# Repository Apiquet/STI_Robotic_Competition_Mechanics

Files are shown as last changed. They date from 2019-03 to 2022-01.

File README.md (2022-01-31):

EPFL Robotics Competition: mechanical design repository. 

Complete description of the job done here: https://apiquet.com/2019/08/20/epfl-robotics-competition/

# Description

The goal of the EPFL (Ecole Polytechnique Fédérale de Lausanne) Robotics Competition is to build an autonomous recycling robot.  This robot, built from scratch, must recognizes any bottle (thanks to a camera), catch it, then bring it to a recycling area.

Azzano Guilhem, Erbacher Pierre and I formed the Green Eye team, Winner of the 2019 Edition.

My responsibilities were:

- modeling the collector mecanism to catch the bottles and the system to store them: https://apiquet.com/2019/08/20/epfl-robotics-competition/

- visual recognition using Python and/or C++ to recognize the bottles and guide the robot to them: https://apiquet.com/2019/06/02/visual-recognition/

- Triangularization of the Robot’s position and orientation from an homemade Beacon: https://apiquet.com/2019/06/13/beacon/

# Our robot

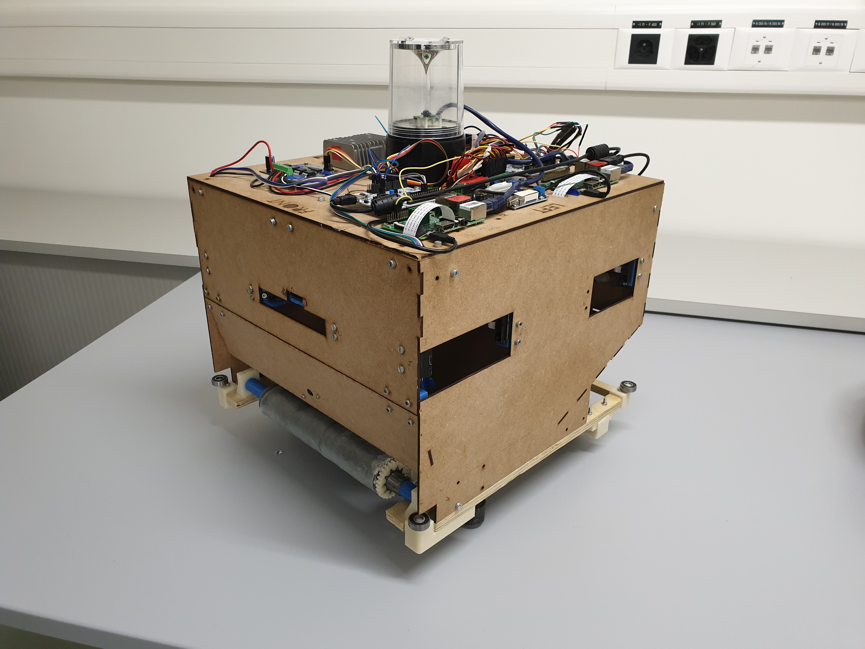
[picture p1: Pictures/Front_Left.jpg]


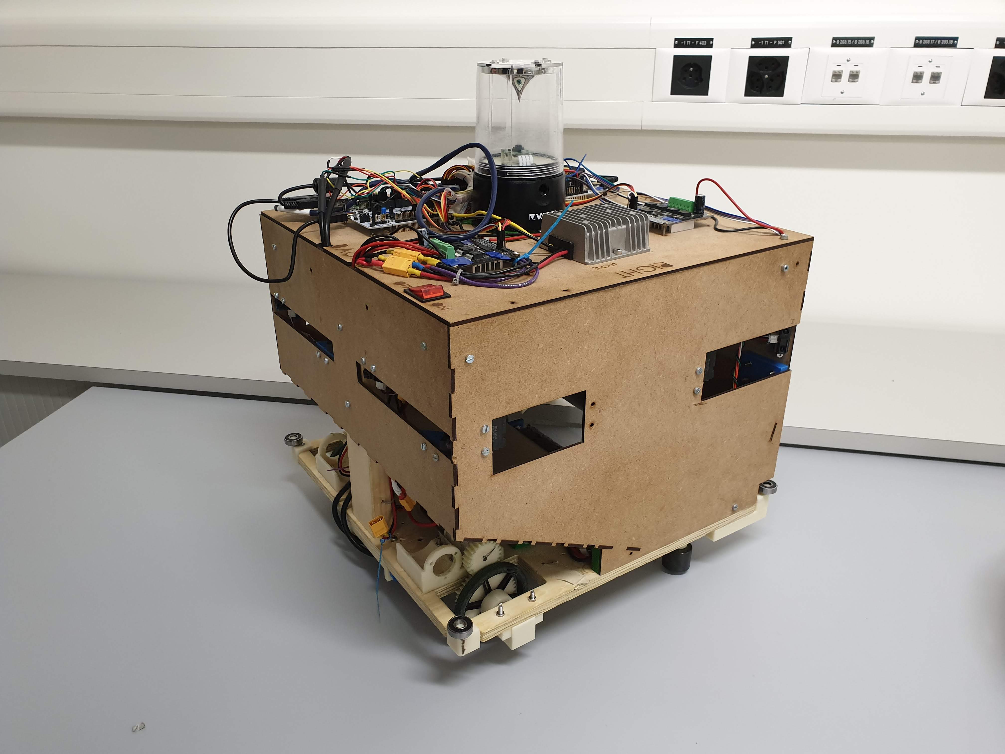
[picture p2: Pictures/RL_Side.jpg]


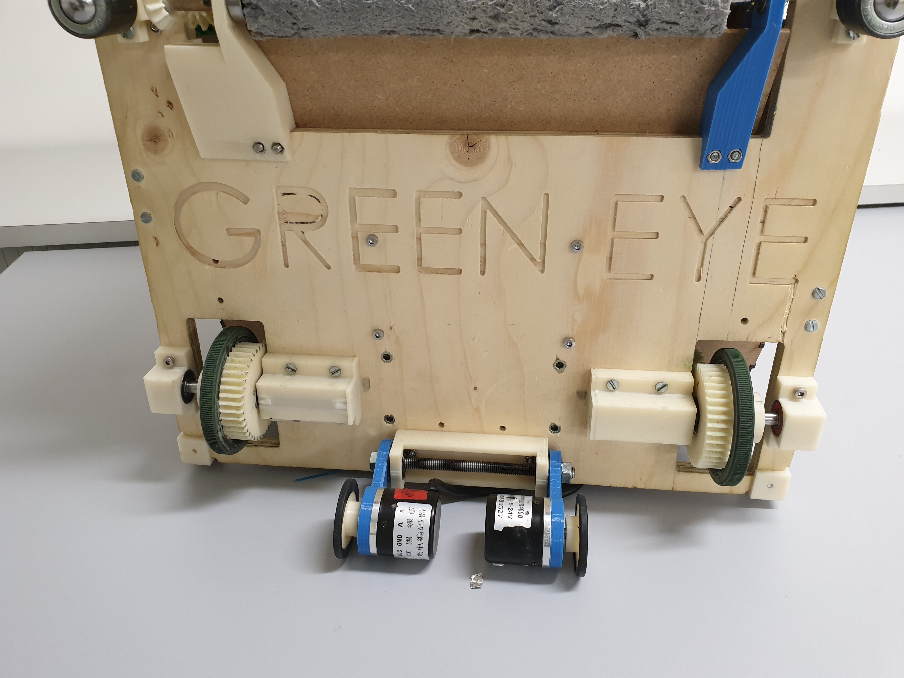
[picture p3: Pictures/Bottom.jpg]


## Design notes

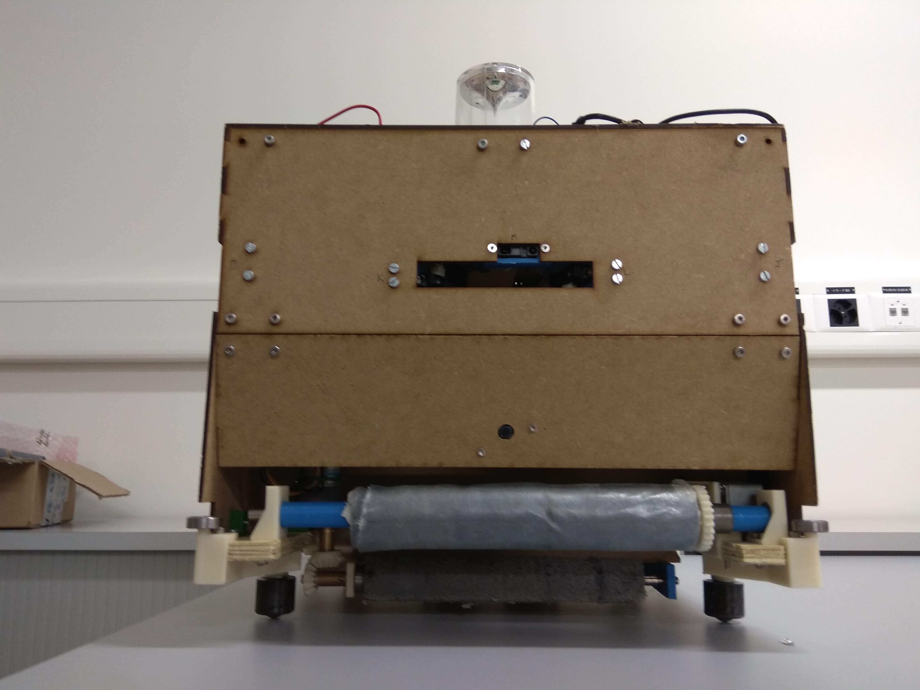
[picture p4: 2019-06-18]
Pictures/RL_Front.jpg

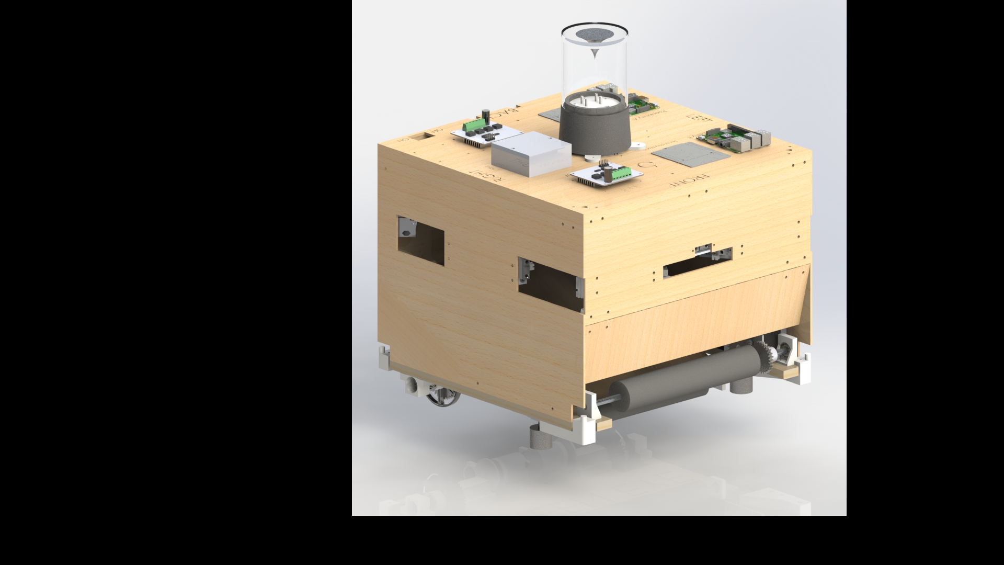
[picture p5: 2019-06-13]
Render_1.JPG

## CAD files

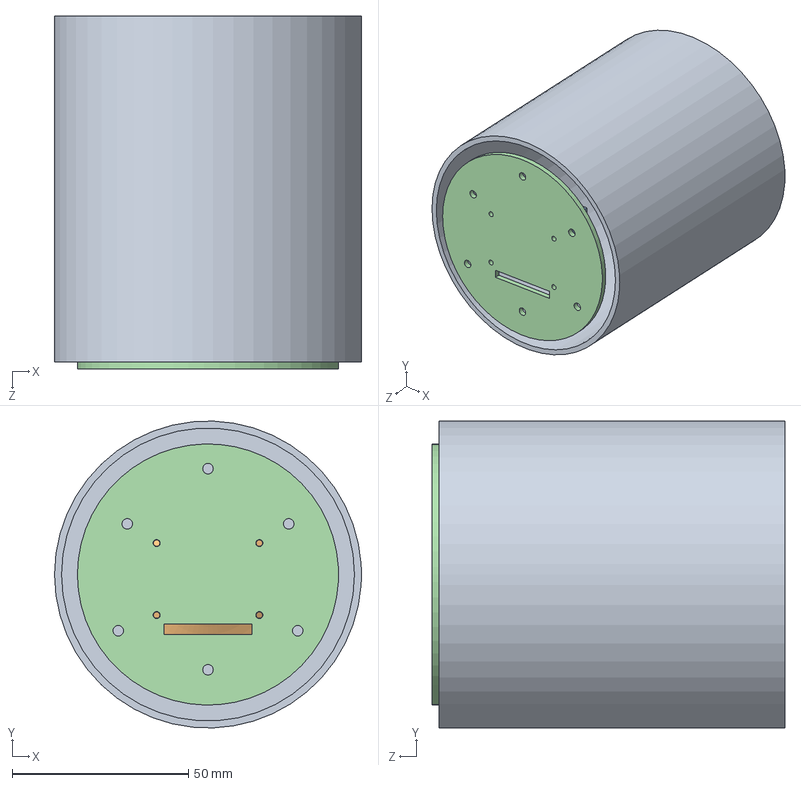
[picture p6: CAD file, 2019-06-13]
Cam_support/V2/glass+cone.SLDASM
87.0 x 87.0 x 100.0 mm
Camera_Case
Camera_Support

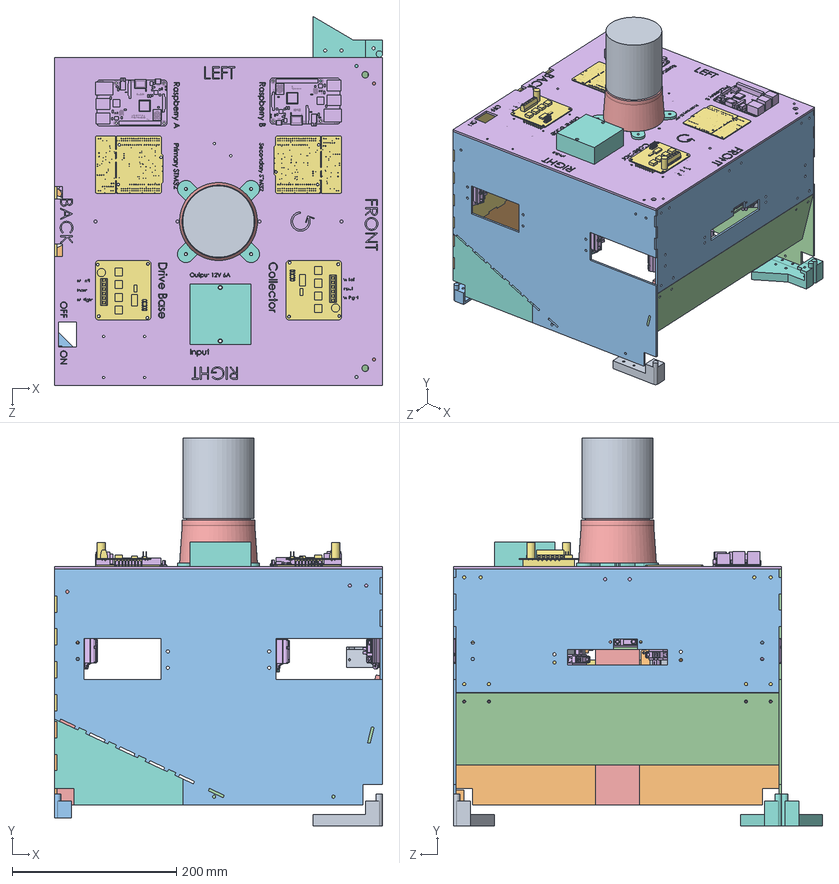
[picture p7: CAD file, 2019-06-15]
Divers/Cosmetics assembly.SLDASM
400.0 x 472.7 x 450.0 mm
Corner_Bearing_Holder
Panel_Right_Holder
Panel_Right
Panel_Left
Pole_Wood_Back
Pole_Wood
Panel_Back
Panel_Bottom_Right_Side
Panel_Bottom_Left_Side
Panel_Bottom_Back
Panel_Top_Front
Panel_Bottom_Front
Panel_Top_Holder x 2
Panel_Roof
NUCLEO-F411RE x 2
base_cam_support
glass
Camera_Support
mount_glass
Rpi3Bplus x 2
2x15A_lite x 2
DC8-40V_DC12V
Corner_Roof
MirrorCorner_Roof
MirrorCorner_Bearing_Holder
Panel_Top_Front_Square
MirrorPanel_Top_Front_Square
SHARP Sensor x 13
Front_side_sensor_holder x 2
side_sensor_holder
Front_Sensor_holder x 2
Back_Middle_Sensor_Holder x 2
Back_Side_Sensor_Holder x 2
Front_Middle_Sensor_Holder
Mirrorside_sensor_holder
Sensor_Side_Back_V2 x 2
MirrorMirrorCorner_Bearing_Holder
Mirror_Corner_Bearing_Holder

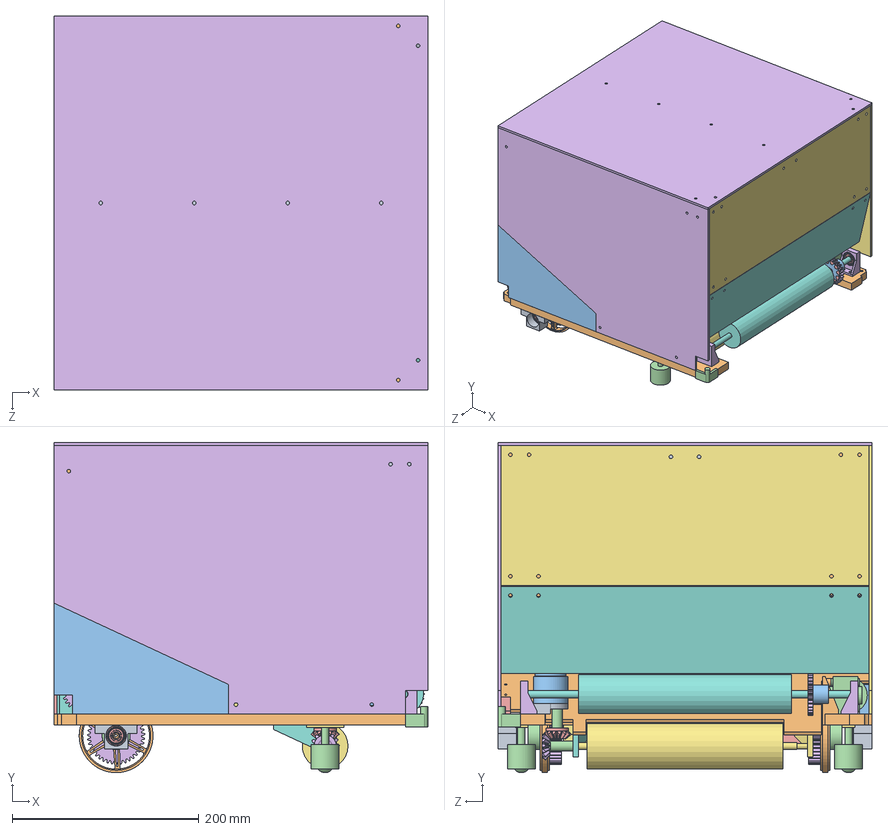
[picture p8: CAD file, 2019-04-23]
Top_Level_Assembly.SLDASM
400.0 x 353.3 x 400.0 mm
re25 x 2
wheel x 2
H38S x 2
Adapter_Wheel x 4
Ball Bearing 608ZZ x 12
spur gear_gb x 8
Bearing Holder Long
Body_Base
Bearing Holder x 2
Wood_base
battery_5.2 x 2
Ball_support x 2
MirrorBearing Holder Long
MirrorBody_Base
Ball_Support_Nut_Holder x 2
Battery_Side_Block x 2
Battery_Blocker x 2
hex_hub x 2
pinion_gear
bevel_gear
Roller_Bottom
Roller_Top
Bearing16_7.9_5mm
Bearing15_5.9_5mm
10-tooth sprocket x 2
motor_roller
Gear_Sprocket_Adapter x 2
Top_Roller_Holder x 2
Bottom_Left_Roller_Holder
Bottom_Right_Roller_Holder
Bottom_Motor_Holder
Top_Motor_Holder
GM37

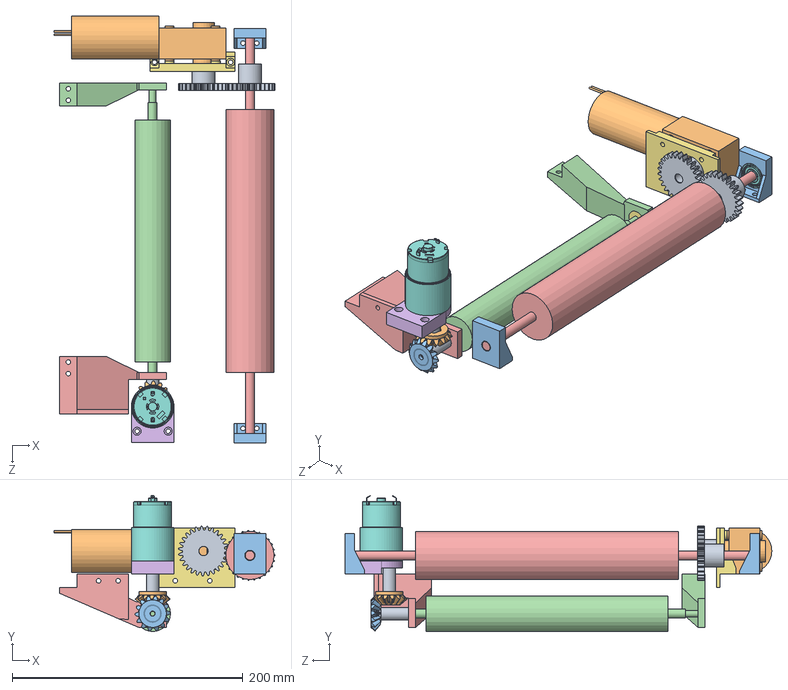
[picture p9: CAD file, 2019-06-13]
Collector_Mechanism/Collector_Mechanism.SLDASM
191.7 x 118.0 x 370.1 mm
hex_hub x 2
pinion_gear
bevel_gear
Roller_Bottom
Roller_Top
Bearing16_7.9_5mm
Bearing15_5.9_5mm
Ball Bearing 608ZZ x 2
10-tooth sprocket x 2
motor_roller
Top_Roller_Holder x 2
Bottom_Left_Roller_Holder
Bottom_Right_Roller_Holder
Bottom_Motor_Holder
Top_Motor_Holder
GM37
Gear_Sprocket_Fusion x 2

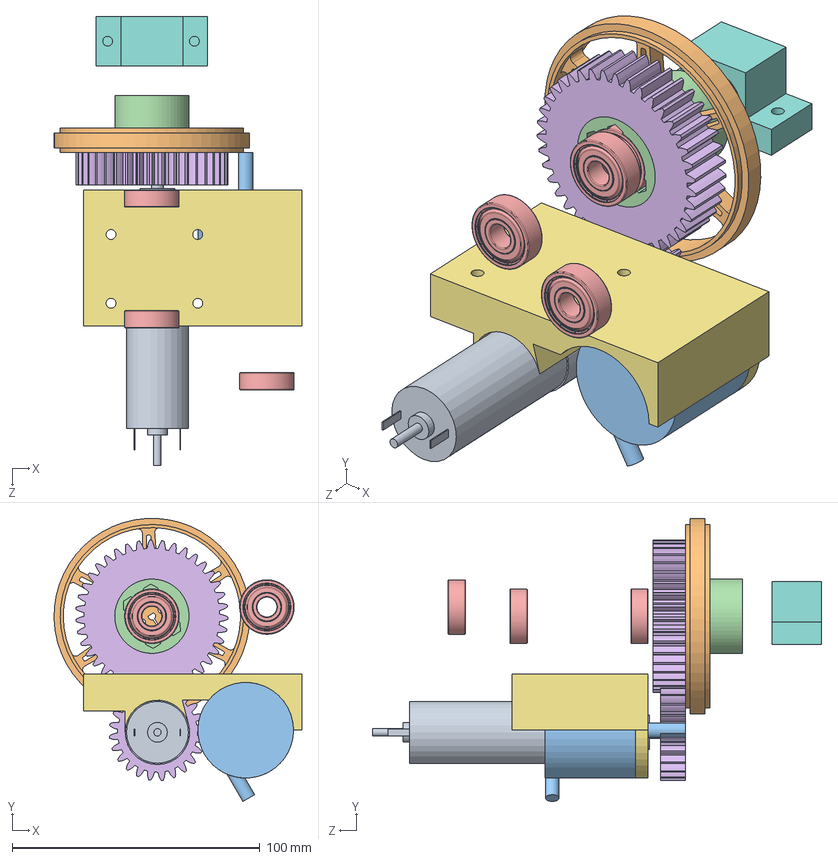
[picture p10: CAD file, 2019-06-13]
Drive_Base/MirrorDrive_Base.SLDASM
100.0 x 114.2 x 181.2 mm
re25
wheel
H38S
Adapter_Wheel x 2
Ball Bearing 608ZZ x 6
spur gear_gb x 2
MirrorBody_Base
Bearing Holder

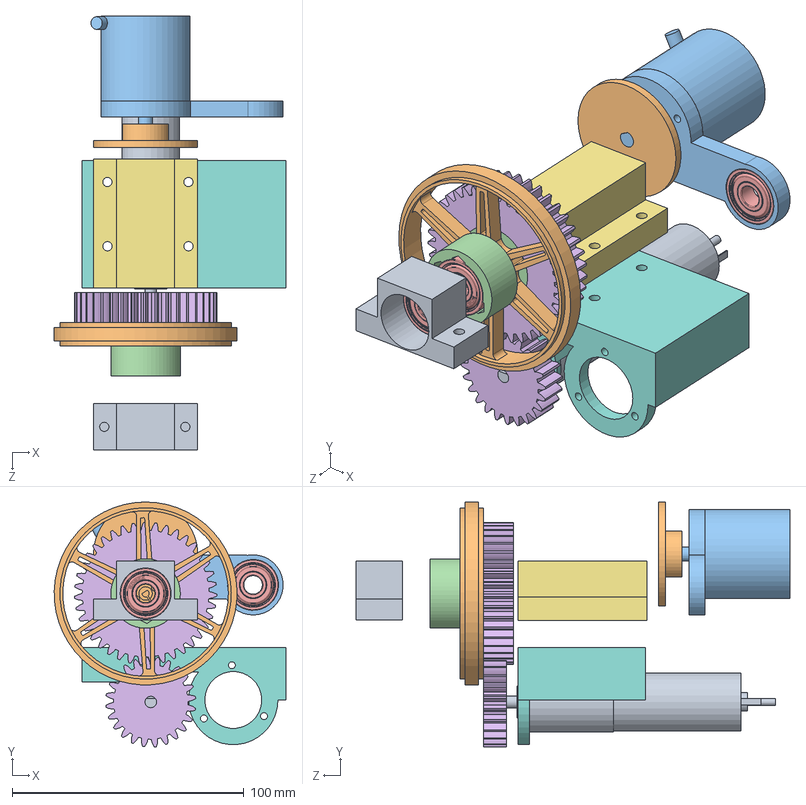
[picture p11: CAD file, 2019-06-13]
Drive_Base/Drive_Base.SLDASM
100.0 x 105.8 x 187.4 mm
re25
wheel
H38S
Adapter_Wheel x 2
Ball Bearing 608ZZ x 6
spur gear_gb x 2
Bearing Holder Long
Body_Base
Bearing Holder
Encodeur_Wheel
Axial_Encoder_Holder

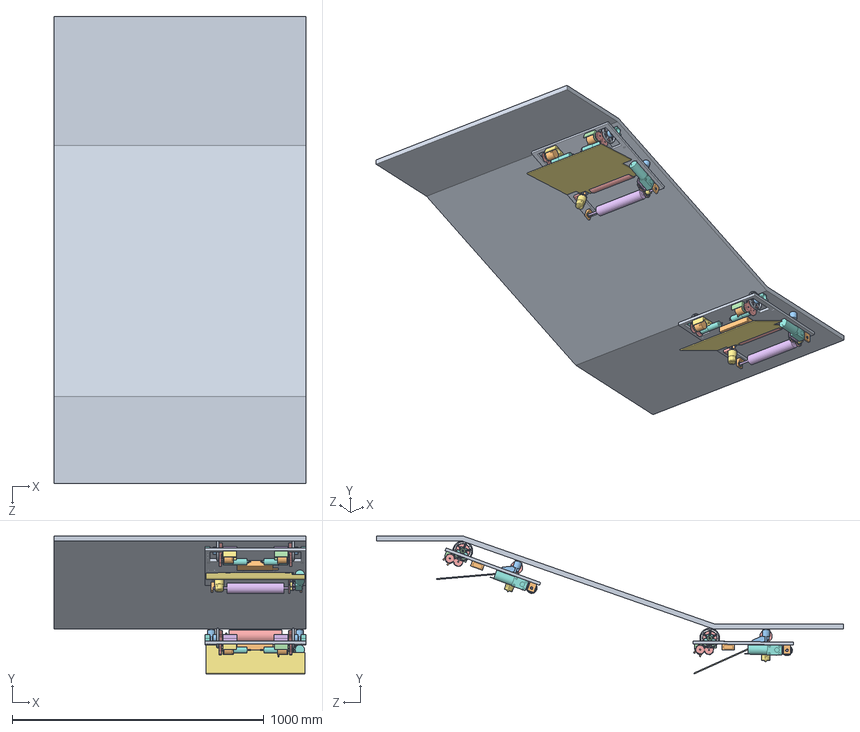
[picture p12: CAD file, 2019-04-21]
Field/Ramp_Test_Assembly.SLDASM
1000.0 x 547.7 x 1855.6 mm
Ramp_Field
hex_hub x 4
pinion_gear x 2
bevel_gear x 2
Roller_Bottom x 2
Roller_Top x 2
GM37 x 2
re25 x 4
wheel x 4
H38S x 4
Adapter_Wheel x 8
Ball Bearing 608ZZ x 24
spur gear_gb x 16
Bearing Holder Long x 4
Body_Base x 2
Bearing Holder x 4
Wood_base x 2
battery_5.2 x 2
Ball_support x 4
MirrorBody_Base x 2
Bearing16_7.9_5mm x 2
Bearing15_5.9_5mm x 2
10-tooth sprocket x 4
motor_roller x 2
Gear_Sprocket_Adapter x 4
Top_Roller_Holder x 4
Bottom_Left_Roller_Holder x 2
Bottom_Right_Roller_Holder x 2
Bottom_Motor_Holder x 2
Top_Motor_Holder x 2
Wooden_Ramp x 2

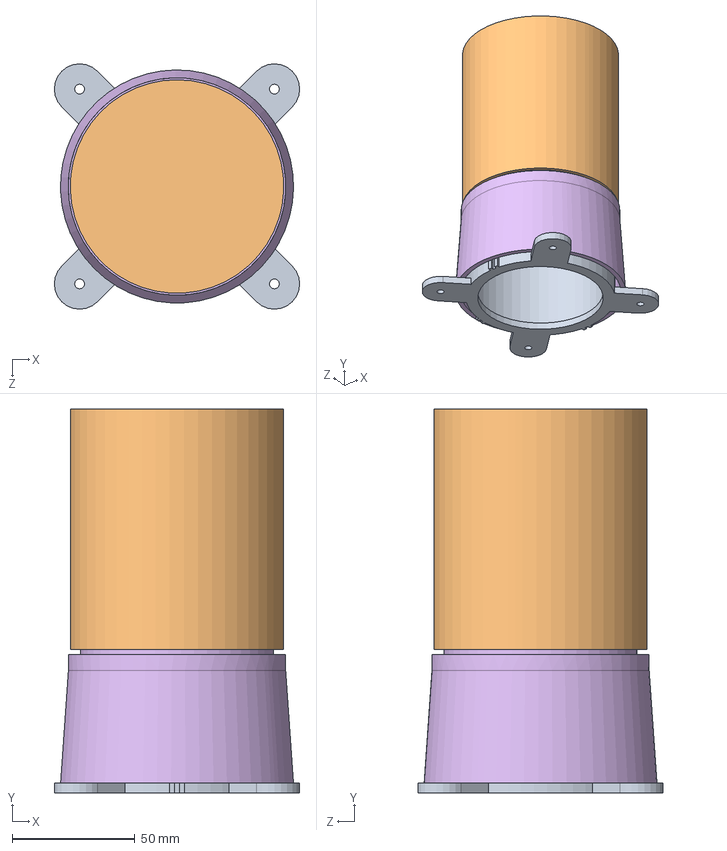
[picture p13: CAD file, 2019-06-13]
Cam_support/V2/Finale.SLDASM
100.0 x 156.5 x 100.0 mm
base_cam_support
glass
Camera_Support
mount_glass

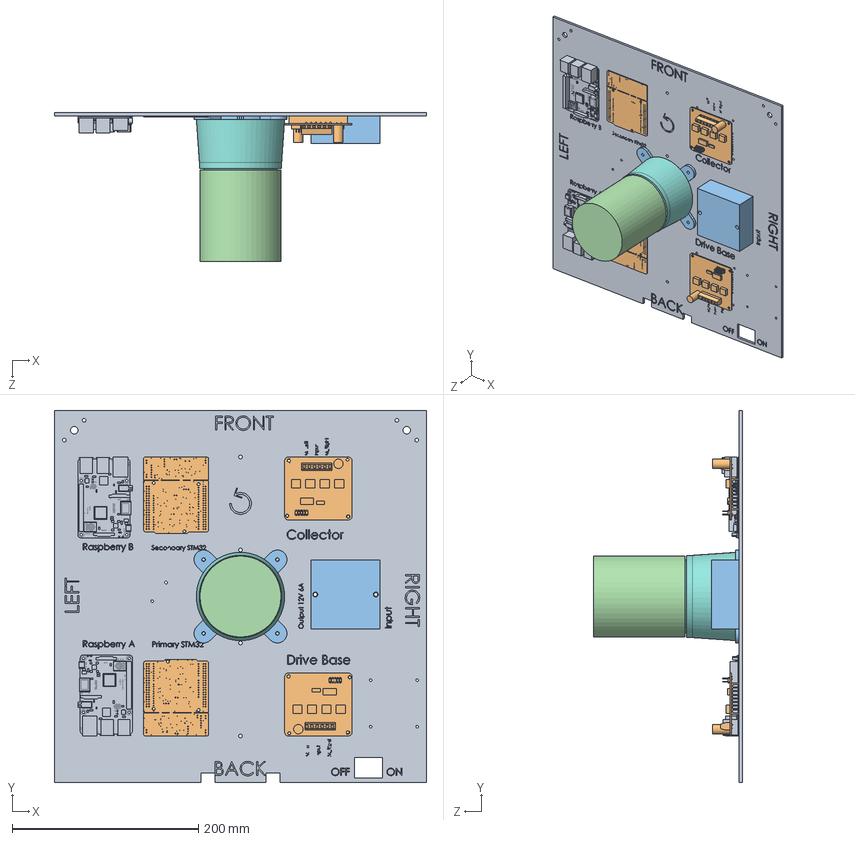
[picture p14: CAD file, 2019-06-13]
Divers/Top_Roof.SLDASM
400.0 x 400.0 x 159.8 mm
Panel_Roof
NUCLEO-F411RE x 2
base_cam_support
glass
Camera_Support
mount_glass
Rpi3Bplus x 2
2x15A_lite x 2
DC8-40V_DC12V

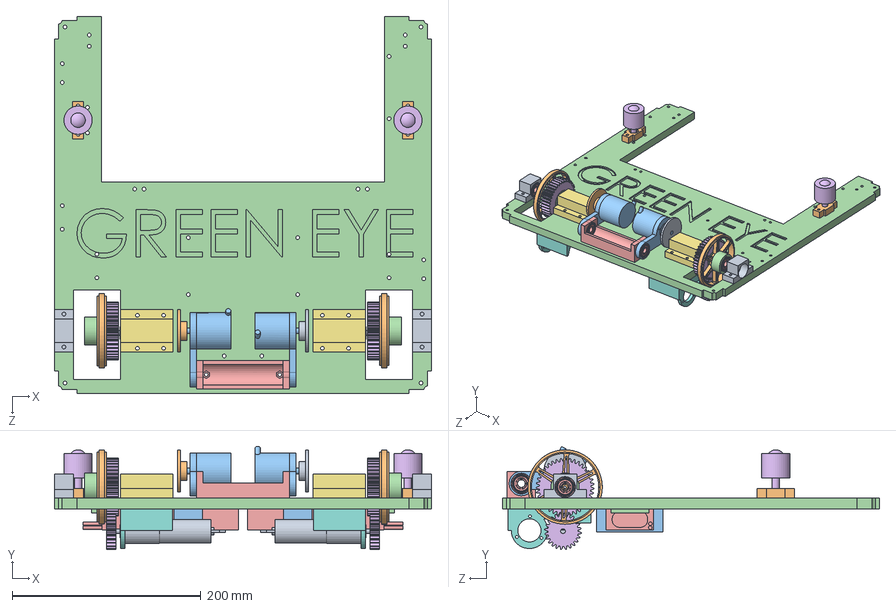
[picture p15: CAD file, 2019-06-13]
Drive_Base/Bottom_base.SLDASM
400.0 x 109.3 x 400.0 mm
re25 x 2
wheel x 2
H38S x 2
Adapter_Wheel x 4
Ball Bearing 608ZZ x 14
spur gear_gb x 4
Bearing Holder Long
Body_Base
Bearing Holder x 2
Encodeur_Wheel
Axial_Encoder_Holder x 2
Wood_base
battery_5.2 x 2
Ball_support x 2
MirrorBearing Holder Long
MirrorBody_Base
MirrorEncodeur_Wheel
Ball_Support_Nut_Holder x 2
Battery_Side_Block x 2
Battery_Blocker x 2
Axis_Encodeur_Holder

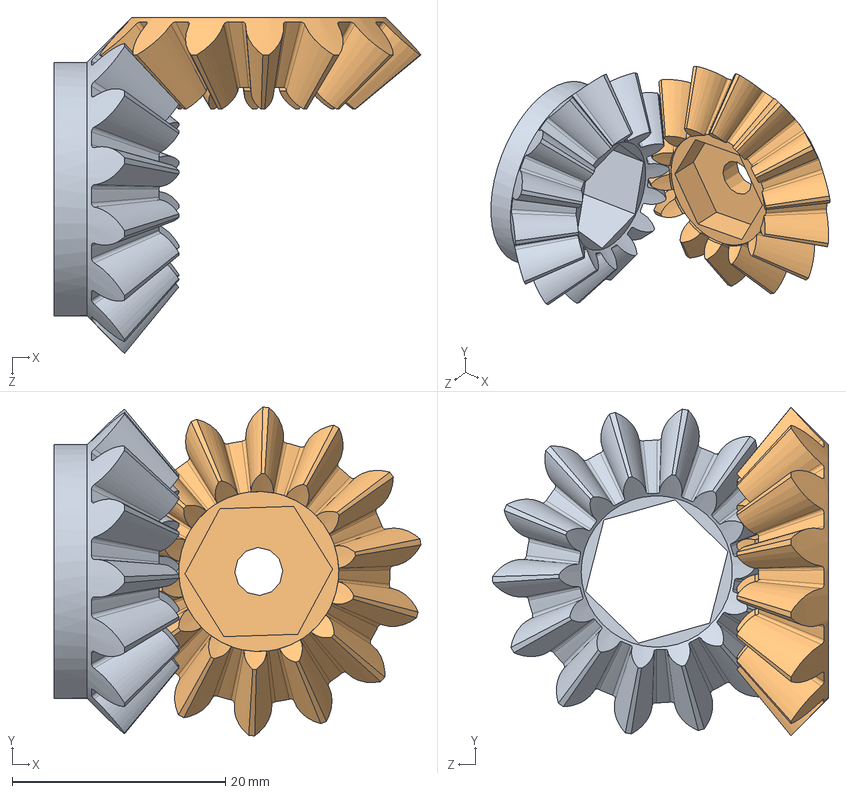
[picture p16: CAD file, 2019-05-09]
Collector_Mechanism/PivotandBevel.SLDASM
34.4 x 30.8 x 31.5 mm
pinion_gear
bevel_gear

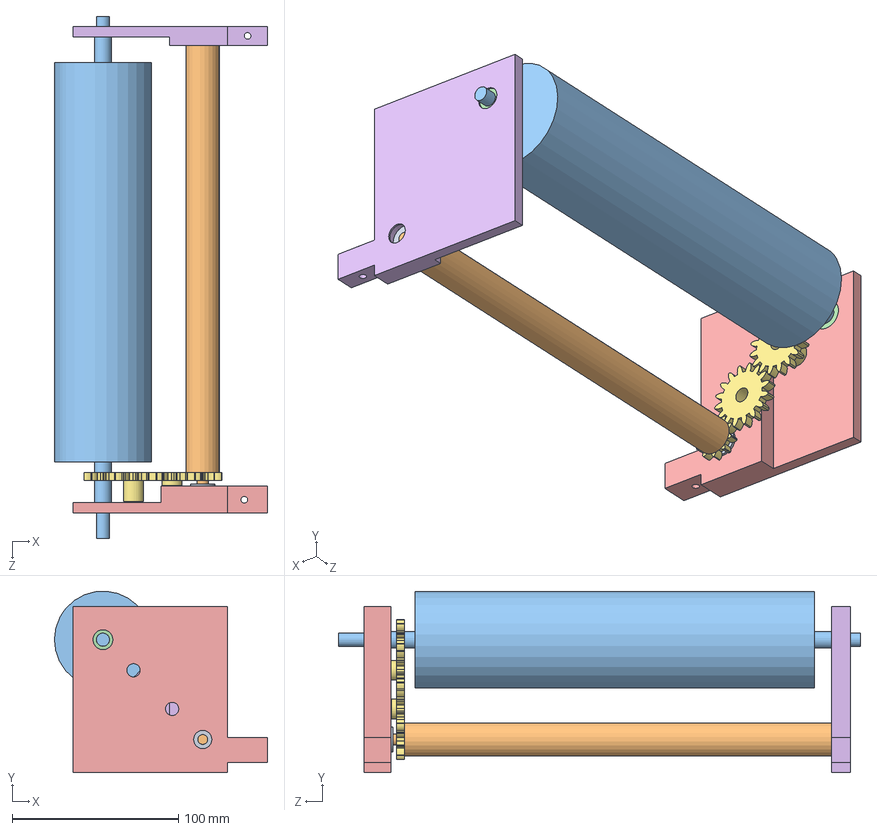
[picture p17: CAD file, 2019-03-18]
Prototype_Bottle_Mechanism/V2_Assembly_Collect_Mechanism.SLDASM
128.2 x 109.1 x 313.9 mm
Bearing15_5.9_5mm x 2
Roller_1
Roller_2
Bearing16_7.9_5mm x 2
roller_holder_v2_left
roller_holder_v2_right
spur gear_gb x 4

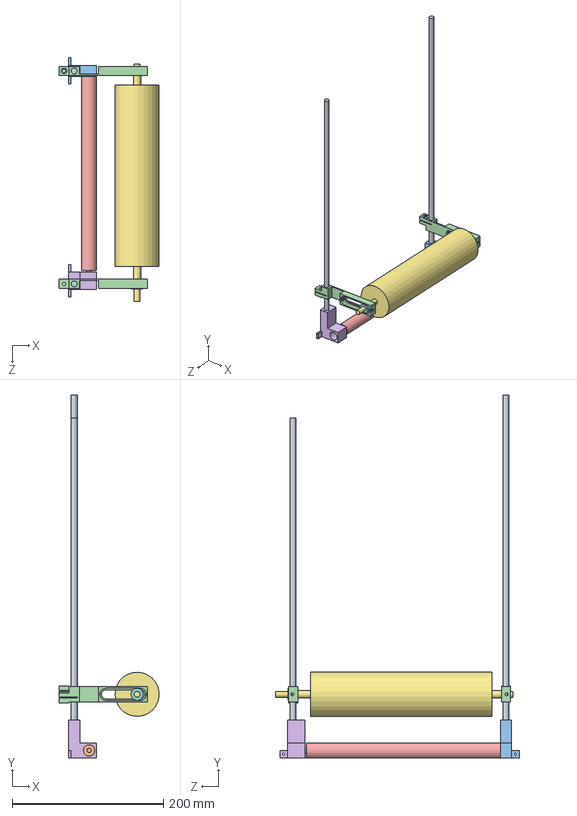
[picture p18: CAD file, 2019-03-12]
Prototype_Bottle_Mechanism/Assembly_Collect_Mechanism.SLDASM
132.5 x 480.3 x 322.3 mm
8mmAxis x 2
Bearing15_5.9_5mm x 2
Holder_1_roller
Holder_2_roller x 2
Roller_1
Holder_1_roller_long
Roller_2
Bearing16_7.9_5mm x 2

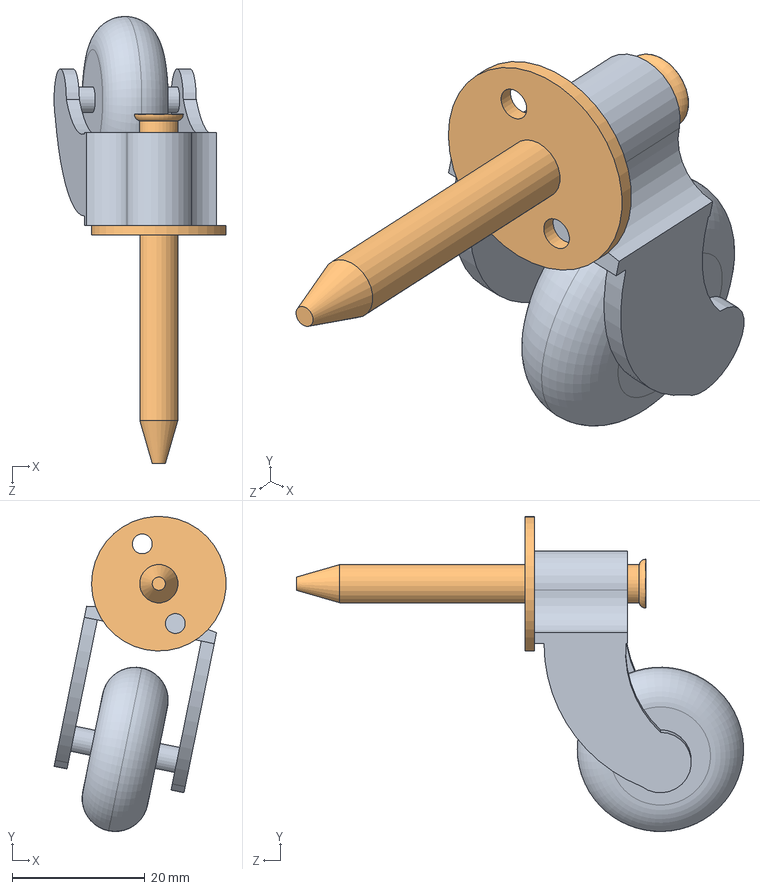
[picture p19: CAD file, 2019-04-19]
Drive_Base/Support_wheel.SLDASM
25.9 x 47.5 x 67.4 mm
Base_support_wheel
Top_support_wheel

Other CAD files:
Collector_Mechanism/Pre_Design_Collector_Assembly.SLDASM
Drive_Base/MirrorDrive_Base1.SLDASM
Divers/MirrorPart1^Pre_Design_Collector_Assembly.sldprt
AxialBlock.SLDPRT
Cam_support/V1/Cam_hat.SLDPRT
Cam_support/V1/base_cam.SLDPRT
Cam_support/V2/Camera_Case.SLDPRT
Cam_support/V2/Camera_Support.SLDPRT
Cam_support/V2/Cone.SLDPRT
Cam_support/V2/base_cam_support.SLDPRT
Cam_support/V2/glass.SLDPRT
Cam_support/V2/joint.SLDPRT
Cam_support/V2/mount_glass.SLDPRT
Cam_support/front_cam/Camera_Case.SLDPRT
Collector_Mechanism/10-tooth sprocket.SLDPRT
Collector_Mechanism/Back_Motor_Roller_Support.SLDPRT
Collector_Mechanism/Ball Bearing 608ZZ.SLDPRT
Collector_Mechanism/Bearing15_5.9_5mm.SLDPRT
Collector_Mechanism/Bearing16_7.9_5mm.SLDPRT
Collector_Mechanism/Bottom_Left_Roller_Holder.SLDPRT
Collector_Mechanism/Bottom_Motor_Holder.SLDPRT
Collector_Mechanism/Bottom_Right_Roller_Holder.SLDPRT
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

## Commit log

2019-03-12 Adding the prototype bottle mechanism Adding old cad of the RE25 motors
    [8mmAxis.SLDPRT, Assembly_Collect_Mechanism.SLDASM, Bearing15_5.9_5mm.SLDPRT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]
2019-03-12 Changing path + deleting stl
    [Assembly_Collect_Mechanism.SLDASM, Holder_1_roller_long.STL, Holder_2_Roll.STL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]
2019-03-12 Adding roller holder right n left
    [battery.SLDPRT, body.SLDPRT, re25.SLDPRT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]
2019-03-13 Adding assembly V2 bottle mechanism
    [V2_Assembly_Collect_Mechanism.SLDASM]
2019-03-13 Added gears and correction for the right holder
    [Big_Gear_Roler.SLDPRT, Small_gear_Roller1.SLDPRT, Small_gear_Roller2.SLDPRT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]
2019-03-14 Adding roller motor modelling
    [motor_roller.SLDPRT]
2019-03-14 motor GM-37 holes missing
    [motor_GM37.SLDPRT]
2019-03-14 H38S holes missing
    [H38S.SLDPRT]
2019-03-14 Adding electronics board 2x15A_lite
    [2x15A_lite.SLDPRT]
2019-03-14 powerboard robopoly + MDD10A_REV2.0
    [MDD10A_REV2.0.SLDPRT, powerboard_robopoly.SLDPRT]
2019-03-14 Adding GM37 + H38S + 2x15A_lite
    [2x15A_lite.SLDPRT, GM37.SLDPRT, H38S.SLDPRT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]
2019-03-14 add support for cam
    [Cam_Support.SLDASM, OVA5647.SLDASM, OVA5647.SLDPRT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]
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2019-03-14 Adding holes powerboard robopoly + MDD10A
    [MDD10A_REV2.0.SLDPRT, powerboard_robopoly.SLDPRT]
2019-03-16 Adding axis + hex hub + collect mechanism v2
    [10mmAxis.SLDPRT, 10mmAxis_then_8mm.SLDPRT, 8mmAxis_then_6mm.SLDPRT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]
2019-03-16 Auto stash before merge of "master" and "origin/master"
    [Ball Bearing 608ZZ.SLDPRT, Drive_Base.SLDASM, wheel.SLDPRT]
2019-03-16 57mm between the rollers
    [collect_mechanism_v2.SLDASM, roller_holder_right_v2.SLDPRT, roller_holder_right_v2_template.SLDPRT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]
2019-03-17 New mount for right motor
    [Bearing22_9.9_5mm - Copy.SLDPRT, Drive_Base.SLDASM, collect_mechanism_v2.SLDASM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]
2019-03-17 Centering hole left roller
    [collect_mechanism_v2.SLDASM, motor_support_up.SLDPRT, roller_holder_right_v2.SLDPRT]
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2019-03-17 Adding adapter for gear
    [AdapterhubHex.SLDPRT, collect_mechanism_v2.SLDASM, hex_hub.SLDPRT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]
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2019-03-17 Adding hole for second gear
    [big_motor_support.SLDPRT, collect_mechanism_v2.SLDASM]
2019-03-17 Adding holes for screw to support motor
    [big_motor_support.SLDPRT, collect_mechanism_v2.SLDASM]
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2019-03-17 Correction Left holder and motor
    [big_motor_support.SLDPRT, collect_mechanism_v2.SLDASM, motor_roller.SLDPRT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]
2019-03-17 Correction Right plate
    [collect_mechanism_v2.SLDASM, roller_holder_right_v3.SLDPRT]
2019-03-18 Adding Materials + Adding general bottom assembly
    [10mmAxis_then_8mm.SLDPRT, AdapterhubHex.SLDPRT, Bearing Holder.SLDPRT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]
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2019-03-18 Adding holes right plate
    [collect_mechanism_v2.SLDASM, roller_holder_right_v3.SLDPRT]
2019-03-19 Correction driving base
    [Body_Base.SLDPRT, Bottom_base.SLDASM, Drive_Base.SLDASM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]
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2019-03-19 Decrease printing time of motor support
    [big_motor_supportv2.SLDPRT]
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2019-03-22 Cleaning repo, replacing gears in the driving base
    [2x15A_lite.SLDPRT, Bottom_base.SLDASM, Drive_Base.SLDASM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]
2019-03-22 Correction holder roller high right
    [Bottom_base.SLDASM, MirrorBody_Base.SLDPRT, MirrorDrive_Base.SLDASM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]
2019-03-22 Correction left high roller holder
    [Bottom_base.SLDASM, collect_mechanism_v2.SLDASM, left_motor_support.SLDPRT]
2019-03-22 Correction holder left and right low
    [Bottom_base.SLDASM, collect_mechanism_v2.SLDASM, roller_low_holder_left.SLDPRT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]
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2019-03-24 Wider bearing holder + side of the driving base
    [Bearing Holder.SLDPRT, Bottom_base.SLDASM, Drive_Base.SLDASM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]
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2019-03-24 Updating drive base
    Change gear for the 2nd motor.
    bearing holder stronger
    [Bottom_base.SLDASM, Drive_Base.SLDASM, Gear_Moteur.SLDPRT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]
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2019-03-27 Fixing interferences
    [Bottom_base.SLDASM, PivotandBevel..SLDASM, Roller_1.SLDPRT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]
2019-03-27 Fixing rollers
    [Bottom_base.SLDASM, PivotandBevel..SLDASM, Roller_1.SLDPRT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]
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2019-04-12 Adapt structure to easily remove front and back
    [Bottom_base.SLDASM, MirrorBody_Base.SLDPRT, MirrorDrive_Base1.SLDASM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]
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2019-04-16 Adding new sides and good orientation for right and left sensors
    [Bottom_base.SLDASM, MirrorBody_Base.SLDPRT, MirrorDrive_Base1.SLDASM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]
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2019-04-17 Creating rails for the front and the back sides
    [Bottom_base.SLDASM, MirrorBody_Base.SLDPRT, MirrorDrive_Base1.SLDASM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]
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2019-04-18 Updating front and back sensors to 60 degrees
    [Bottom_base.SLDASM, MirrorBody_Base.SLDPRT, MirrorDrive_Base1.SLDASM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]
2019-04-19 Cleaning bottom assembly of sensors and side panel files
    [Bottom_base.SLDASM, Drive_Base.SLDASM, MirrorBody_Base.SLDPRT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]
2019-04-19 Cleaning Mirror base of the repetitive error
    [Bottom_base.SLDASM, MirrorBody_Base.SLDPRT, MirrorDrive_Base.SLDASM]
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2019-04-19 Add test files for the ramp
    Robot is too low to climb the ramp, back plate is touching
    [Bottom_base.SLDASM, Ramp_Test_Assembly.SLDASM]
2019-04-19 Test for the ramp once at the top
    Everything touch, this is definitively wrong
    [Ramp_Test_Assembly.SLDASM]
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2019-04-19 Setting up new distance for encoder and motor
    [Bearing Holder.SLDPRT, Drive_Base.SLDASM]
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2019-04-19 Drive_base updated with the correct height and good mates
    [Drive_Base.SLDASM]
2019-04-19 Driving base almost finish
    Wood Base : Updated for thickness accuracy
    Drive Base: Setup mate
    [Drive_Base.SLDASM, Wood_base.SLDPRT]
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2019-04-19 Clearance of the wheel adapter and gear
    [Drive_Base.SLDASM]
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2019-04-20 Cleaning Repo +Redesign of the roller
    Redesigning the bottom roller for the sake of clarity and dimensions
    [Roller_Bottom.SLDPRT, high_roller_left_support.SLDPRT, left_motor_support.SLDPRT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]
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2019-04-20 Redesigning top roller
    Wrong dimensions corrected
    [Roller_Top.SLDPRT]
2019-04-20 Correcting again the bevel and pinion which keep being wrongly replaced
    +Removing old roller files
    [PivotandBevel..SLDASM, Roller_1.SLDPRT, Roller_2.SLDPRT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]
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2019-04-20 Correction of the hub design which wasn't fully defined and with few alignment error
    [PivotandBevel.SLDASM, bevel_gear.sldprt, hex_hub.SLDPRT]
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2019-04-20 Fixing dimensions
    Fixing dimensions
    [Bottom_base.SLDASM, Pre_Design_Collector_Assembly.SLDASM, Ramp_Test_Assembly.SLDASM]
2019-04-20 exaggerating the ramp angle for simulation
    Simulation seems ok
    [Ramp_Field.SLDPRT, Ramp_Test_Assembly.SLDASM]
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2019-04-21 Creating adapter for the sprocket, must be tested
    [Gear_Sprocket_Adapter.SLDPRT]
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2019-04-21 Top Motor Holder
    I'm not sure about that one, looks weak though
    [Top_Motor_Holder.SLDPRT]
2019-04-21 Redesign a proper ramp
    [Pre_Design_Collector_Assembly.SLDASM, Wooden_Ramp.SLDPRT]
2019-04-21 Fixing minor issue on the driving base
    Increasing ramp size
    [Bearing Holder Long.SLDPRT, Bottom_Left_Roller_Holder.SLDPRT, Bottom_Motor_Holder.SLDPRT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]
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2019-04-22 Corner for holding bearings redesigned
    [Corner_Bearing_Holder.sldprt]
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2019-04-22 Fixing the ball support
    [Ball_Support_Nut_Holder.SLDPRT, Wood_base.SLDPRT]
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2019-04-22 Updating design, final version before CNC of the bottom plate
    [Battery_Side_Block.SLDPRT, Bottom_Left_Roller_Holder.SLDPRT, Bottom_Motor_Holder.SLDPRT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]
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2019-04-23 Multiple features, read description
    Bottom Plate has been CNC with these dimensions and holes
    Adding pole for top support
    Adding Side of the robot, and back.
    [Battery_Side_Block.SLDPRT, Bottom_Motor_Holder.SLDPRT, Bottom_base.SLDASM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]
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2019-04-23 Shorting cable for interference issue
    [H38S.SLDPRT]
2019-04-23 Adding more holes into panels to consolidate the robot
    [Bottom_base.SLDASM, Drive_Base.SLDASM, MirrorDrive_Base.SLDASM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]
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2019-04-23 Fixing error in holes of the wood base
    [Battery_Side_Block.SLDPRT, Bottom_Motor_Holder.SLDPRT, Bottom_base.SLDASM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]
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2019-04-23 strengthen top motor holder
    [Collector_Mechanism.SLDASM, Top_Level_Assembly.SLDASM, Top_Motor_Holder.SLDPRT]
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2019-04-23 Fixing sprocket
    [10-tooth sprocket.SLDPRT, Gear_Sprocket_Adapter.SLDPRT]
2019-04-23 Fixing holes in wood base
    [Battery_Side_Block.SLDPRT, Bottom_base.SLDASM, Collector_Mechanism.SLDASM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]
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2019-04-24 New corner because of the radius of the CNC
    [Collector_Mechanism.SLDASM, Corner_Bearing_Holder.sldprt, Cosmetics assembly.SLDASM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]
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2019-05-03 Remove collision raspberry pi Side sensor held
    [Corner_Roof.SLDPRT, Cosmetics assembly.SLDASM, Front_side_sensor_holder.sldprt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]
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2019-05-03 Back sensor holder almost done
    Todo : Holes in the cosmetics
    Wire space
    [Back_Side_Sensor_Holder.SLDPRT, Cosmetics assembly.SLDASM]
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2019-05-05 Redesign for a lower ramp
    [Battery_Blocker.SLDPRT, Battery_Side_Block.SLDPRT, Bottom_Left_Roller_Holder.SLDPRT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]
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2019-05-12 Side sensors raised, confirmed
    Test has been successfull
    [Cosmetics assembly.SLDASM]
2019-05-12 Implementation of two way of mouting encoders.
    1st : Vertical spring, not working well, fine tuning is needed and is woobly
    2st with axial mount through bearing. Currently being printed.
    [AxialBlock.SLDPRT, Axial_Encoder_Holder.SLDPRT, Axis_Encodeur_Holder.SLDPRT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]
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2019-05-22 fixing assembly error
    [Bottom_base.SLDASM, Cosmetics assembly.SLDASM, MirrorMirrorCorner_Bearing_Holder.sldprt]
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2019-05-30 strengthen different part
    [Back_Motor_Roller_Support.SLDPRT, Collector_Mechanism.SLDASM, Corner_Bearing_Holder.sldprt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]
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2019-06-13 Beacon correction
    [Camera_Support.SLDPRT, Cone.SLDPRT, Cosmetics assembly.SLDASM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]
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2019-06-15 Adding missing sensor
    [Cosmetics assembly.SLDASM, Panel_Right.SLDPRT, SHARP Sensor.SLDPRT]
